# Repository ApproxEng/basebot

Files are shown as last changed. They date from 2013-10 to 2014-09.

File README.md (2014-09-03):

BaseBot
=======

Basebot is a set of laser cut templates, hardware recommendations and guides and software for a cheap wheeled robotics platform.

Get the SVG or DXF files for the acrylic parts from this repository, and see the wiki for [the bill of materials](http://basebot.org/w/index.php?title=Bill_of_Materials) and [assembly instructions](http://basebot.org/w/index.php?title=Assembly_Instructions) - these don't currently include control or power circuitry, but you'll end up with a solid chassis including motors ready for your controller of choice...

The latest version (v16) looks like this (lacking any form of control circuitry!)

Current chassis

This has evolved quite a bit from an earlier version (v4 or so)



Developed at Makespace in Cambridge, UK (http://www.makespace.org)

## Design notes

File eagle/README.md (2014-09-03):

Files for BaseBot circuit boards. At the moment this consists solely of the very simple power distribution board; this simplifies connection of the battery, power switches and servos to whatever control board you're using but doesn't do anything particularly clever.

Any Eagle files here must be kept sufficiently simple that they can be opened with the no-cost version of Eagle!

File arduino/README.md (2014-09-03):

This is a place for arduino sketches for the BaseBot, one sub-folder per sketch.

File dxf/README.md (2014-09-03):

These are DXF files generated from the SVG files in the /svg directory. They should not be regarded as the original source, so don't edit them and expect edits to be persisted!

The opaque.dxf and transparent.dxf files are for the opaque and transparent parts respectively of the version of the BaseBot which came to EMF2014 - if you want a duplicate of that model you need to cut those parts, and then obtain the rest of the bits and assemble them. Details of this process can be found on the basebot wiki, see the home page link for more information.

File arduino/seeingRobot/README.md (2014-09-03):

This is a very naive control algorithm using a CMU Pixy v5 to home in on colour signatures. It uses a simple hysterisis mechanism rather than any kind of PID controller and therefore judders around like a crazy thing. It appeared to amuse the children though at the Science Centre demo!

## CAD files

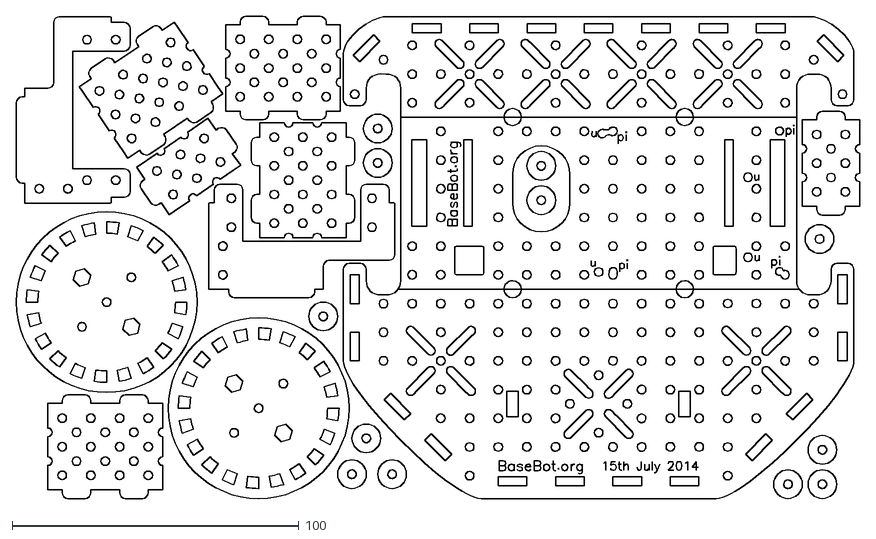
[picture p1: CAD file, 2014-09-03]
dxf/transparent.dxf
294.0 x 168.2

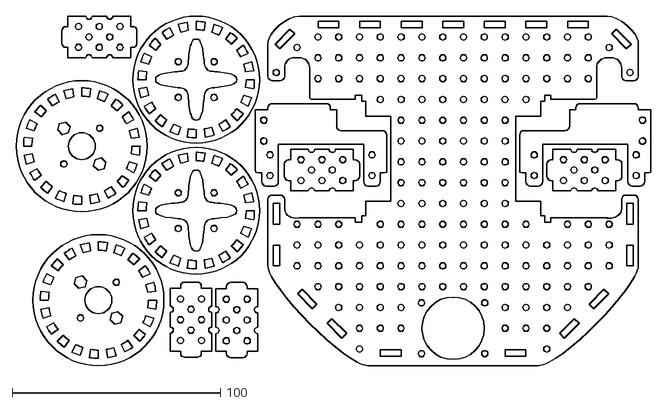
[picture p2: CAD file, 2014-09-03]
dxf/opaque.dxf
305.0 x 168.1

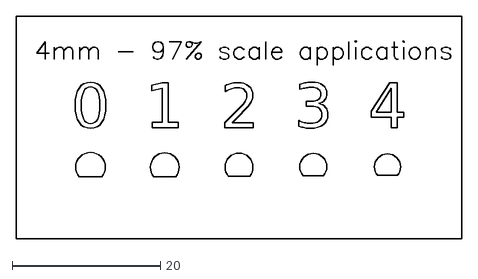
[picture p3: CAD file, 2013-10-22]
dxf/wheel-mount-calibration.dxf
60.0 x 30.0

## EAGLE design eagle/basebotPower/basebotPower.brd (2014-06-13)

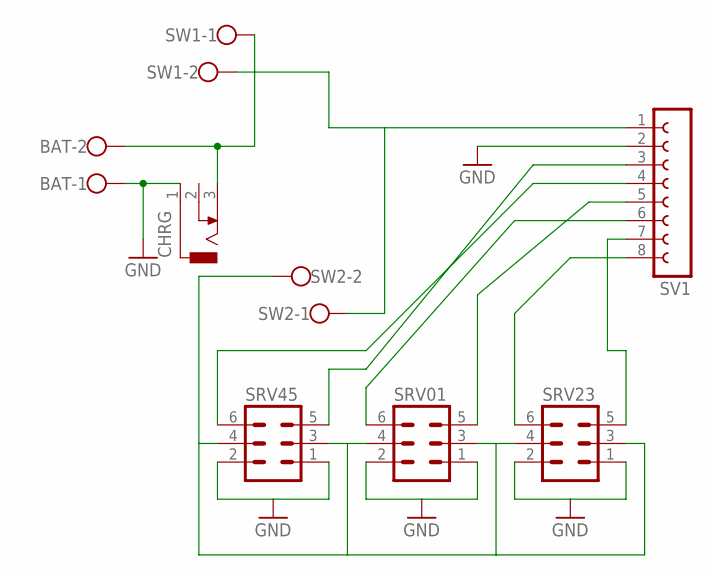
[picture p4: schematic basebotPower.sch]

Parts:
BAT: W237-102
CHRG: DCJ0303
SRV01, SRV23, SRV45: MA03-2
SV1: FE08-1; FE08
SW1, SW2: W237-102

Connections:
GND: BAT.1, CHRG.1, SRV01.1, SRV01.2, SRV23.1, SRV23.2, SRV45.1, SRV45.2, SV1.2
unnamed: BAT.2, CHRG.3, SW1.1
unnamed: SRV23.6, SV1.8
unnamed: SRV23.5, SV1.7
unnamed: SRV45.6, SV1.4
unnamed: SRV45.5, SV1.3
unnamed: SRV01.6, SV1.6
unnamed: SRV01.5, SV1.5
unnamed: SRV01.3, SRV01.4, SRV23.3, SRV23.4, SRV45.3, SRV45.4, SW2.2
SERVOPWR: SV1.1, SW1.2, SW2.1

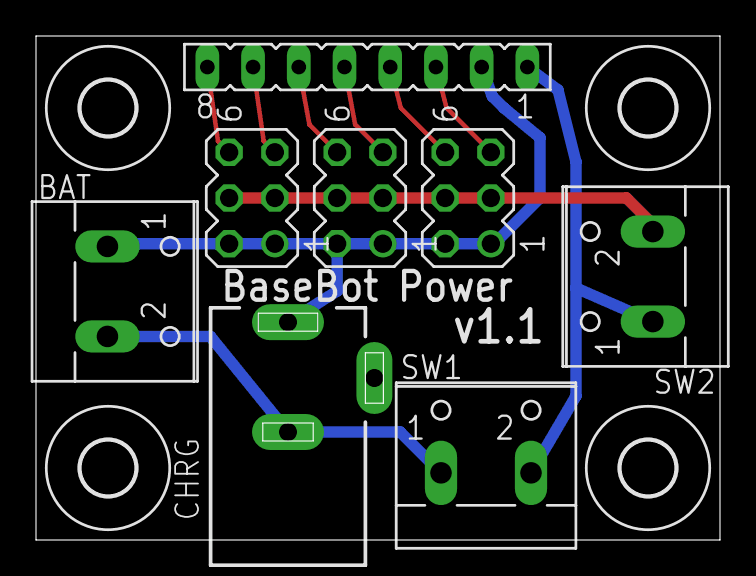
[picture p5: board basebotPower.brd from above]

Board: 2 copper layers, 38.0 x 28.0 mm, 12 parts (0 on the bottom side), 10 nets.

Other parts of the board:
U$1, U$2, U$3, U$4: 3,0

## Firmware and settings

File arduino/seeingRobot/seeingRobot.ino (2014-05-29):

#include <SPI.h>
#include <Pixy.h>
#include <Servo.h> 

Pixy pixy;
Servo left, right;
static int leftCentre = 75;
static int rightCentre = 75;
static int centreZone = 50;
static int delta = 10;
static int idealWidth = 150;
static int minWidth = 50;
static int widthHysterisis = 20;

void setup() {
  Serial.begin(9600);
  Serial.print("Basebot says hello!\n");
  left.attach(5);
  right.attach(6);
}

void loop() {
  // Look for the single largest signature, if found.
  int blocks = pixy.getBlocks();
  delay(30);
  if (blocks) {
    int x = pixy.blocks[0].x-160;
    int width = pixy.blocks[0].width;
    left.attach(5);
    right.attach(6);
    if (width > minWidth) {
      Serial.print(x);
      Serial.print("  ");
      if (x > centreZone) {
        turnRight();
      }
      else if (x < -centreZone) {
        turnLeft();
      }
      else {
        if (width < idealWidth - widthHysterisis) {
          forward();
        } 
        else if (width > idealWidth + widthHysterisis) {
          back();
        } 
        else {
          stop();
        }
      }

    }
    Serial.println(x);
  }
  else {
   stop();
  }

}

void forward() {
  Serial.println("Forwards");
  right.write(rightCentre - delta);
  left.write(leftCentre + delta);
}
void back() {
  Serial.println("Run away!");
  right.write(rightCentre + delta);
  left.write(leftCentre - delta);
}
void turnLeft() {
  Serial.println("Left!");
  left.write(leftCentre - delta);
  right.write(rightCentre - delta);
}
void turnRight() {
  Serial.println("Right!");
  right.write(rightCentre + delta);
  left.write(leftCentre + delta);
}
void stop() {
  Serial.println("Stop");
  right.write(rightCentre);
  left.write(leftCentre);
}

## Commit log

2013-10-22 Added SVG and (some) DXF files for the current version of the basebot
    [wheel-mount-calibration.dxf]
2013-10-28 Updated files to new version for 6v batteries and battery pack. Added appropriate bits and pieces for the accessory kits!
2013-11-20 Updated platters and wheel designs
2013-11-22 Added refined version with rounded cornered tabs, extra width for slots etc.
2013-11-22 Expanded slots for motor mounts, some half hearted attempt at page layout.
2014-01-25 Updated to switch to 30mm verticals
2014-01-25 Updated design to latest, including optional fitting for optical encoders on the wheels, expanded options for verticals and refactoring to 30mm uprights.
2014-01-26 Moved risers to 10mm wide to fit on grid spacing, fixed issue with encoder LED mount part colliding with wheel position tuner piece.
2014-02-04 Updated with new pattern designed around using a prop adapter (4mm to 6mm) to anchor the wheels. Still untested!
2014-02-06 Added more platters (optional) as well as re-instating the extra diagonal slot. Still can't actually be used if the H-bridge is in place but if not it's available again now.
2014-05-29 Added motor mounts based on continuous rotation servos
2014-05-29 Updated chassis to reflect change to cr servos, should fit better (but servo horn mount not tested yet). Added binding to centre point, and provided alternative front panel with mount for servo drive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
2014-05-29 Added arduino sketch from science centre demo
2014-06-05 Updated wheel design, added servo cable slots, made centre piece modular, removed side-slots from servo mounts (will require filing of servos, but cleaner)
2014-06-06 Added my (probably broken) attempt at using Eagle to generate a power distribution board.
    [basebotPower.brd, basebotPower.sch]
2014-06-12 Board layout done, sent to OSHPark for fabrication! Will presumably find out whether it's actually correct at some point when they arrive.
2014-06-13 Fixed stupid error in board involving the wrong wiring for the servos, also changed the layout to use screw terminals rather than on board switches, this allows for panel mount (and higher current) s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
    [basebotPower.brd, basebotPower.sch]
2014-06-18 Tweaks to layout, allow for variable distance between servo and edge of platter to accomodate the futuba servos (slightly smaller)
2014-07-10 Updated layout with options for dropped servo mounts to accomodate castors
2014-07-10 Added tripod layout files and dxf layer files for transparent and opaque layers. Trial to test castor, tripod and variable spacing for servos.
    [tripot-opaque.dxf, tripot-translucent.dxf]
2014-07-10 Stupid typos...
    [tripod-opaque.dxf, tripod-translucent.dxf]
2014-07-15 Fixed slot alignment in tripod layout along with wheel servo horn fittings. Still need to a) increase inner wheel hold diameter, and b) add curved front to the tripod layout as the current arrangemen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
    [tripod-opaque.dxf, tripod-translucent.dxf]
2014-07-15 Updated layout, fixed a few bugs and added logos. Added cross markers to top plates and extended front plate to be more useful.
2014-07-22 Fixes slot lengths back to 10mm, the laser kerf already provides more than enough leeway and there's no variation there like there is for thickness.
2014-09-03 Removed old layout file, was overly confusing. Added the start of an alternative to the top and bottom platters to allow a 6xAA battery pack to be accessed from below, not tested yet though.
2014-09-03 Added DXF files for the version of the basebot seen at EMF2014
    [opaque.dxf, transparent.dxf]
2014-09-24 Updated platter layout to allow for deeper servos (such as the turnigy 4309/4303 from hobbyking) and for a 6AA battery holder accessible from underneath the robot. Added reinforcement, not sure how e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
2014-10-15 Widened whole layout somewhat to accommodate reinforcing around battery compartment. Improved general fittings.
2014-10-15 Updated to include random missing holes (oops...)
2014-10-16 Fixed too-narrow battery holder, as well as a few other tweaks to increase the amount of room for servos.
2014-10-30 Added insert to allow the wires from the battery holder to clear the entrance port more easily.
